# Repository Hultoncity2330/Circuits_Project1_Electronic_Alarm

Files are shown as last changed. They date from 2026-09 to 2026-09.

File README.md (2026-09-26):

# Projet Réveil Électronique

Projet de conception d’un **réveil électronique** réalisé sous **KiCad**.  
Le dépôt contient le schéma électronique, le PCB routé, les fichiers du projet KiCad ainsi que plusieurs vues du circuit final.

## Présentation du projet

L’objectif est de concevoir un réveil électronique compact capable d’afficher l’heure sur **4 digits 7 segments**, de gérer l’heure grâce à une horloge temps réel, et de proposer une interface utilisateur simple à l’aide de boutons poussoirs.

Le circuit est organisé autour d’un **Seeed Studio XIAO ESP32-S3**, utilisé comme microcontrôleur principal.

Le PCB comprend notamment :

- un **XIAO ESP32-S3** ;
- un **RTC RV-3028-C7** pour la gestion de l’heure ;
- un **IS31FL3730** pour le pilotage des afficheurs ;
- deux afficheurs doubles **DC56-11EWA**, soit 4 digits au total ;
- un buzzer pour l’alarme ;
- un transistor MOSFET **AO3400A** pour commander le buzzer ;
- quatre boutons poussoirs : `SET`, `ALARM`, `MINUS`, `PLUS` ;
- trois LED d’indication ;
- les résistances et condensateurs nécessaires au fonctionnement du montage.

## Fonctionnement général

Le **XIAO ESP32-S3** constitue le cœur du système.

Le **RV-3028-C7** fournit l’heure au microcontrôleur via le bus **I²C** (`SDA` / `SCL`).

Le **IS31FL3730** est également relié au bus I²C et pilote les deux afficheurs 7 segments. Les deux afficheurs doubles permettent d’obtenir un affichage sur quatre chiffres.

Les boutons permettent l’interaction avec le réveil :

- `SET` : réglage ;
- `ALARM` : gestion de l’alarme ;
- `PLUS` : incrémentation ;
- `MINUS` : décrémentation.

Le buzzer est commandé par le XIAO au travers du MOSFET **AO3400A**.

## Schéma électronique

Le schéma final du projet est disponible ci-dessous :

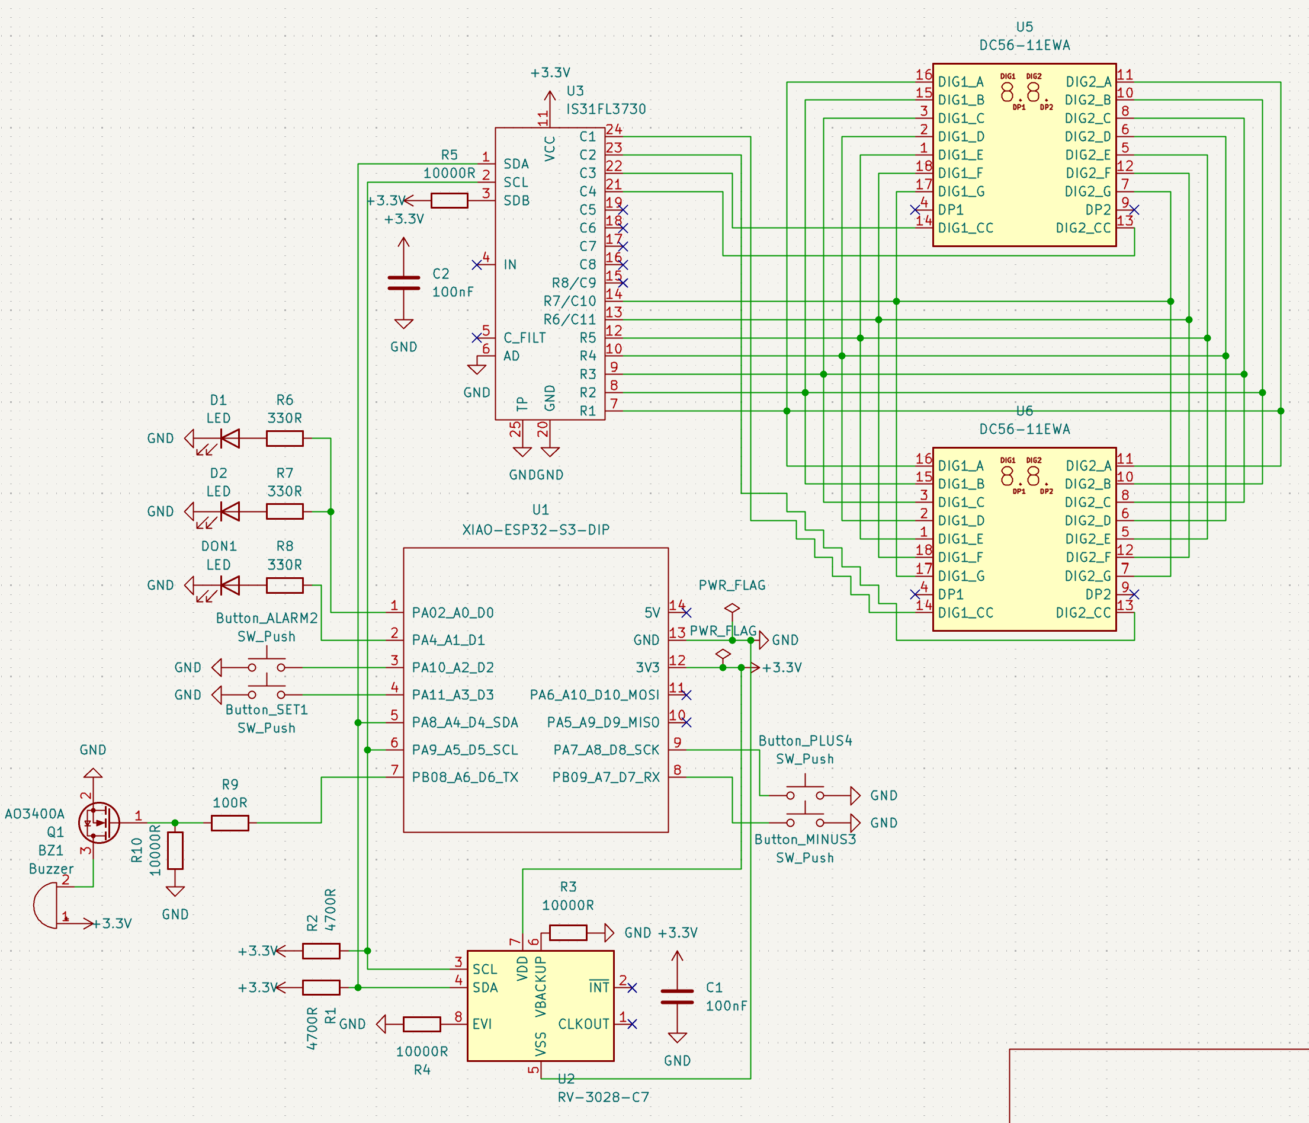
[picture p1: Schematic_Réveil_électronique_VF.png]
Final schematic


Le fichier source KiCad correspondant est :

`Projet_Réveil_électronique.kicad_sch`

## PCB

Le PCB a été placé et routé sous KiCad sur deux couches :

- **F.Cu** : couche cuivre supérieure ;
- **B.Cu** : couche cuivre inférieure.

Le routage utilise également :

- un plan de cuivre **+3.3 V** sur la face supérieure ;
- un plan de masse **GND** sur la face inférieure.

Vue du PCB final :

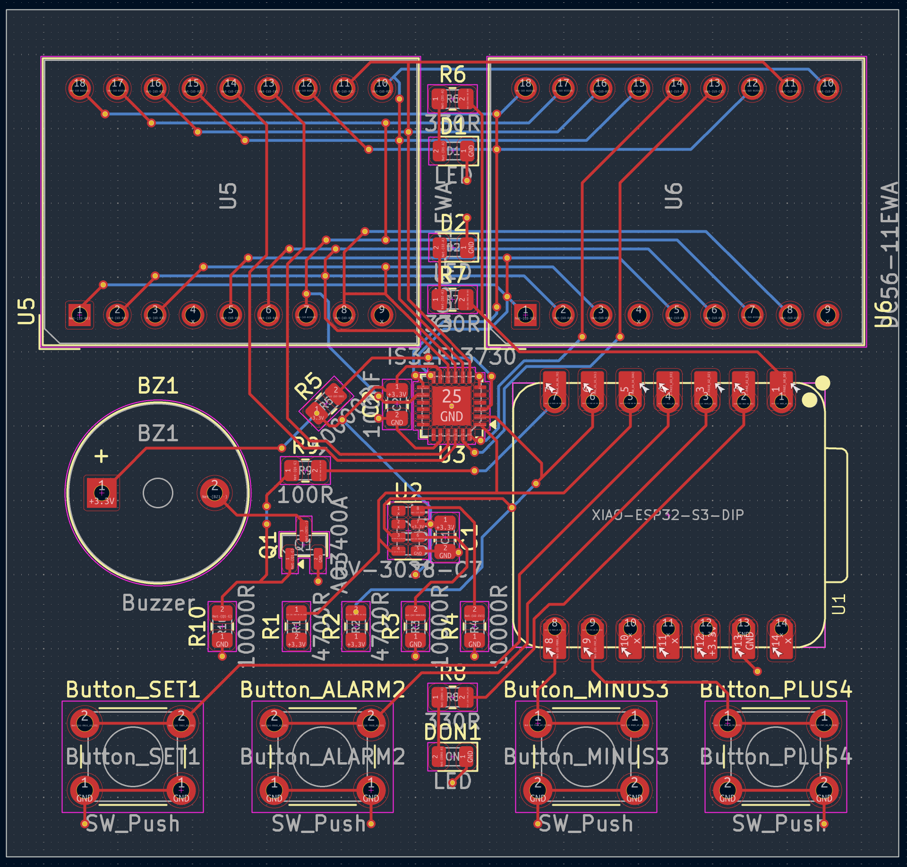
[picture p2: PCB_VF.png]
Final PCB


Le fichier source du PCB est :

`Projet_Réveil_électronique.kicad_pcb`

## Modèle 3D

### Front view

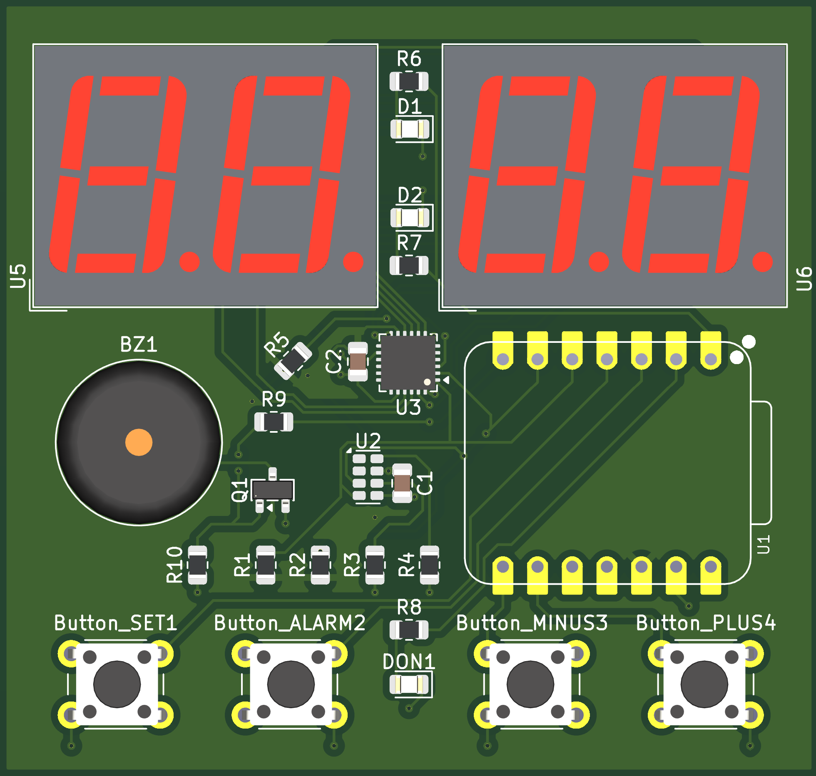
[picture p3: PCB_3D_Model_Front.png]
PCB 3D Front View


### Back view

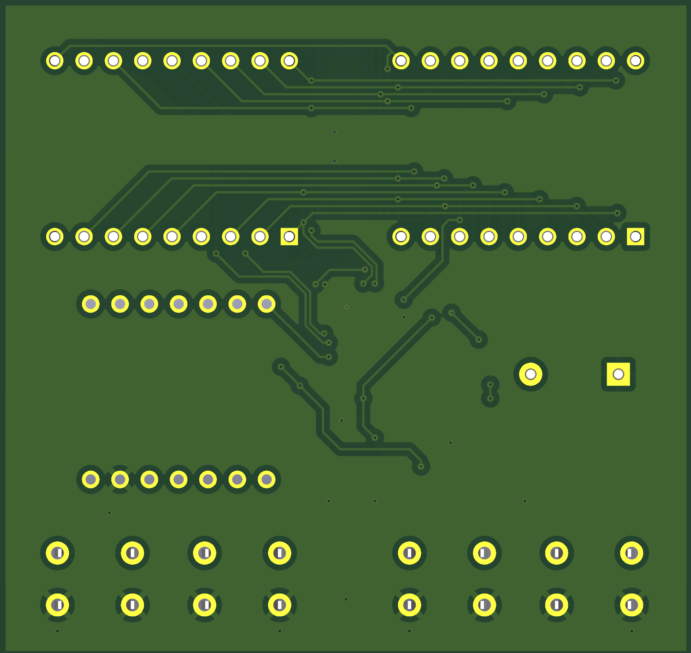
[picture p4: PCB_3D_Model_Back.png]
PCB 3D Back View


### Perspective view

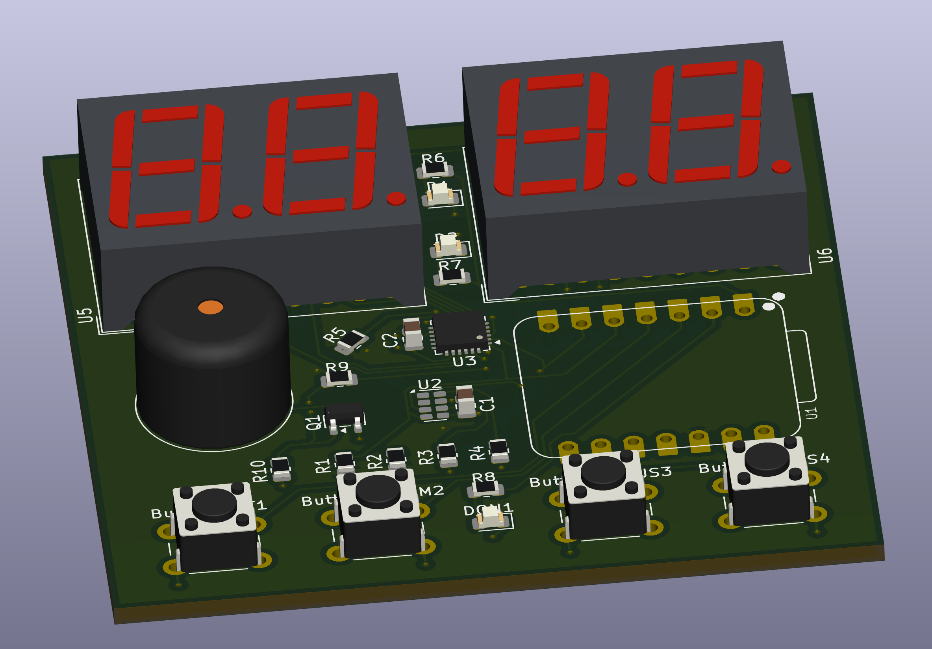
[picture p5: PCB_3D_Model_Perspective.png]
PCB 3D Perspective View


## Validation KiCad

Le projet a été vérifié avec les outils de contrôle de KiCad.

À la fin du routage :

- **ERC** du schéma : validé ;
- **DRC** du PCB : `0` erreur ;
- **Items non connectés** : `0` ;
- **Parité schématique / PCB** : `0` erreur.

Cela permet de vérifier la cohérence électrique et le routage du projet avant la fabrication.

> La validation ERC/DRC ne remplace pas un test physique du PCB assemblé.  
> Le fonctionnement réel doit être confirmé après soudure et mise sous tension.

## Structure du dépôt

```text
.
├── Projet_Réveil_électronique.kicad_pro
├── Projet_Réveil_électronique.kicad_sch
├── Projet_Réveil_électronique.kicad_pcb
├── Schematic_Réveil_électronique_VF.png
├── PCB_VF.png
├── PCB_3D_Model_Front.png
├── PCB_3D_Model_Back.png
├── PCB_3D_Model_Perspective.png
├── .gitignore
└── README.md
```

## Fichiers principaux

| Fichier | Description |
|---|---|
| `Projet_Réveil_électronique.kicad_pro` | Fichier principal du projet KiCad |
| `Projet_Réveil_électronique.kicad_sch` | Schéma électronique |
| `Projet_Réveil_électronique.kicad_pcb` | PCB routé |
| `Schematic_Réveil_électronique_VF.png` | Image du schéma final |
| `PCB_VF.png` | Vue du PCB final |
| `PCB_3D_Model_Front.png` | Vue 3D avant |
| `PCB_3D_Model_Back.png` | Vue 3D arrière |
| `PCB_3D_Model_Perspective.png` | Vue 3D en perspective |

## Auteur

Projet réalisé dans le cadre du cours `Circuits & Embedded Devices` du `21-23/09/2026`.

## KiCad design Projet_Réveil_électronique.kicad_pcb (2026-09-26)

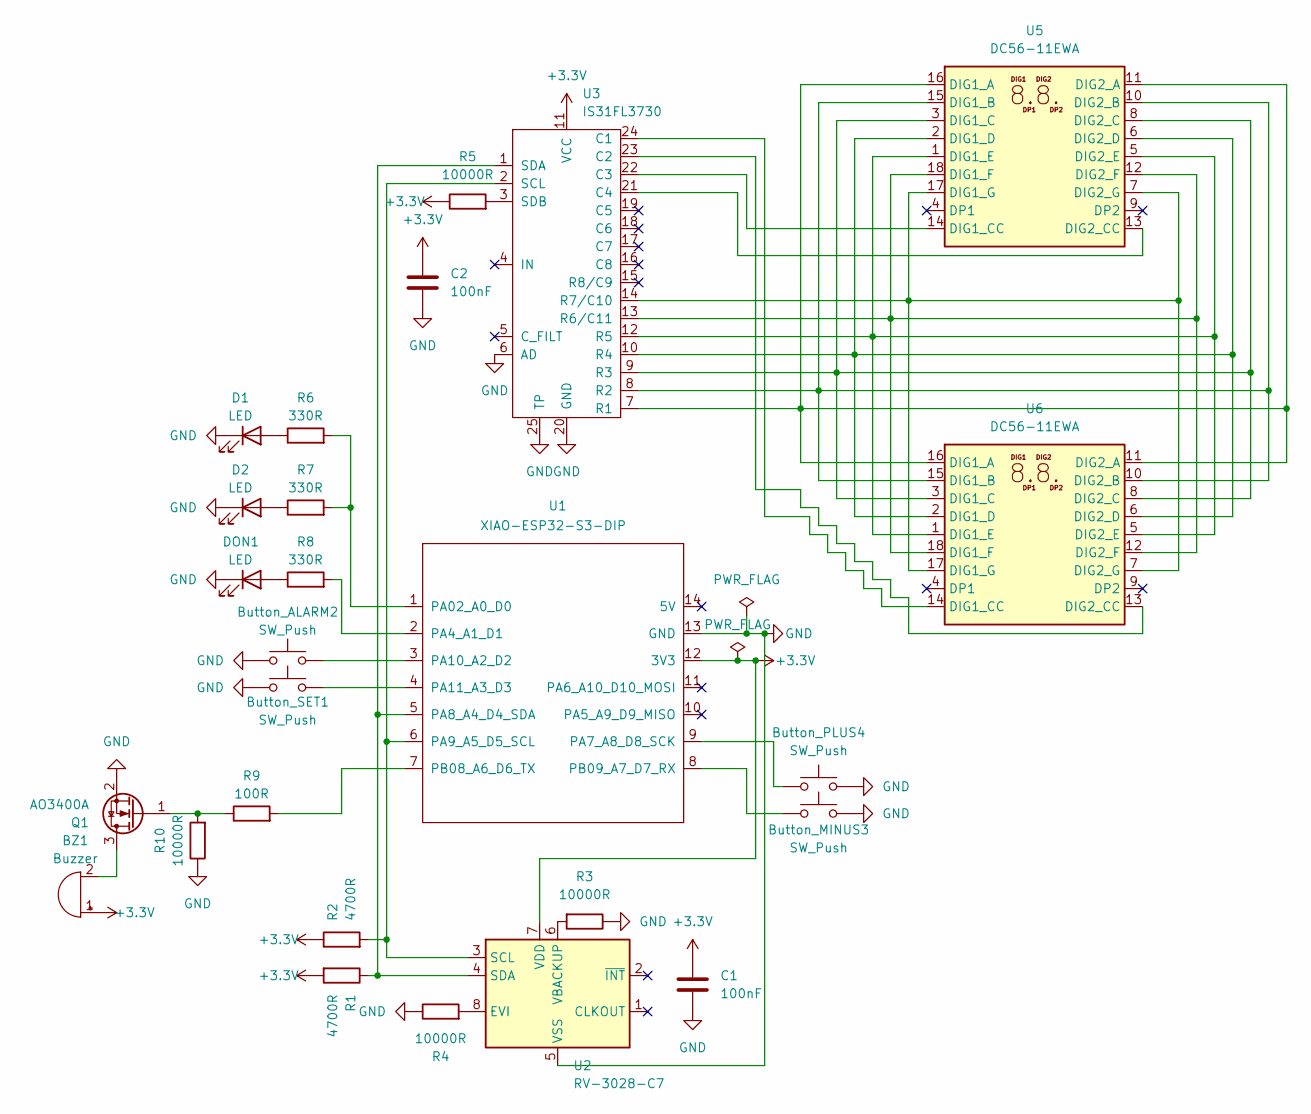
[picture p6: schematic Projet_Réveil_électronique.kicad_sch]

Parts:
BZ1: Buzzer; Buzzer_12x9.5RM7.6
Button_ALARM2: SW_Push; SW_PUSH_6mm
Button_MINUS3: SW_Push; SW_PUSH_6mm
Button_PLUS4: SW_Push; SW_PUSH_6mm
Button_SET1: SW_Push; SW_PUSH_6mm
C1, C2: 100nF; C_0805_2012Metric
D1, D2: LED; LED_0805_2012Metric
DON1: LED; LED_0805_2012Metric
Q1: AO3400A; SOT-23
R1, R2: 4700R; R_0805_2012Metric
R3, R4, R5, R10: 10000R; R_0805_2012Metric
R6, R7, R8: 330R; R_0805_2012Metric
R9: 100R; R_0805_2012Metric
U1: XIAO-ESP32-S3-DIP
U2: RV-3028-C7; MicroCrystal_C7_SON-8_1.5x3.2mm_P0.9mm
U3: IS31FL3730; QFN-24-1EP_4x4mm_P0.5mm_EP2.6x2.6mm
U5, U6: DC56-11EWA; DA56-11SURKWA

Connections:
+3.3V: BZ1.1 (+), C1.1, C2.1, R1.2, R2.1, R5.1, U1.12 (3V3), U2.7 (VDD), U3.11 (VCC)
GND: Button_ALARM2.1, Button_MINUS3.2, Button_PLUS4.2, Button_SET1.1, C1.2, C2.2, D1.1 (K), D2.1 (K), DON1.1 (K), Q1.2 (S), R3.1, R4.1, R10.1, U1.13 (GND), U2.5 (VSS), U3.6 (AD), U3.20 (GND), U3.25 (TP)
unnamed: BZ1.2 (-), Q1.3 (D)
unnamed: D1.2 (A), R6.1
unnamed: D2.2 (A), R7.1
unnamed: DON1.2 (A), R8.1
unnamed: Q1.1 (G), R9.1, R10.2
unnamed: R6.2, R7.2, U1.1 (PA02_A0_D0)
unnamed: R8.2, U1.2 (PA4_A1_D1)
unnamed: Button_PLUS4.1, U1.9 (PA7_A8_D8_SCK)
unnamed: R1.1, U1.5 (PA8_A4_D4_SDA), U2.4 (SDA), U3.1 (SDA)
unnamed: R2.2, U1.6 (PA9_A5_D5_SCL), U2.3 (SCL), U3.2 (SCL)
unnamed: Button_ALARM2.2, U1.3 (PA10_A2_D2)
unnamed: Button_SET1.2, U1.4 (PA11_A3_D3)
unnamed: R9.2, U1.7 (PB08_A6_D6_TX)
unnamed: Button_MINUS3.1, U1.8 (PB09_A7_D7_RX)
unnamed: R4.2, U2.8 (EVI)
unnamed: R3.2, U2.6 (VBACKUP)
unnamed: U3.24 (C1), U6.14 (DIG1_CC)
unnamed: U3.23 (C2), U6.13 (DIG2_CC)
unnamed: U3.22 (C3), U5.14 (DIG1_CC)
unnamed: U3.21 (C4), U5.13 (DIG2_CC)
unnamed: U3.7 (R1), U5.11 (DIG2_A), U5.16 (DIG1_A), U6.11 (DIG2_A), U6.16 (DIG1_A)
unnamed: U3.8 (R2), U5.10 (DIG2_B), U5.15 (DIG1_B), U6.10 (DIG2_B), U6.15 (DIG1_B)
unnamed: U3.9 (R3), U5.3 (DIG1_C), U5.8 (DIG2_C), U6.3 (DIG1_C), U6.8 (DIG2_C)
unnamed: U3.10 (R4), U5.2 (DIG1_D), U5.6 (DIG2_D), U6.2 (DIG1_D), U6.6 (DIG2_D)
unnamed: U3.12 (R5), U5.1 (DIG1_E), U5.5 (DIG2_E), U6.1 (DIG1_E), U6.5 (DIG2_E)
unnamed: U3.13 (R6/C11), U5.12 (DIG2_F), U5.18 (DIG1_F), U6.12 (DIG2_F), U6.18 (DIG1_F)
unnamed: U3.14 (R7/C10), U5.7 (DIG2_G), U5.17 (DIG1_G), U6.7 (DIG2_G), U6.17 (DIG1_G)
unnamed: R5.2, U3.3 (SDB)

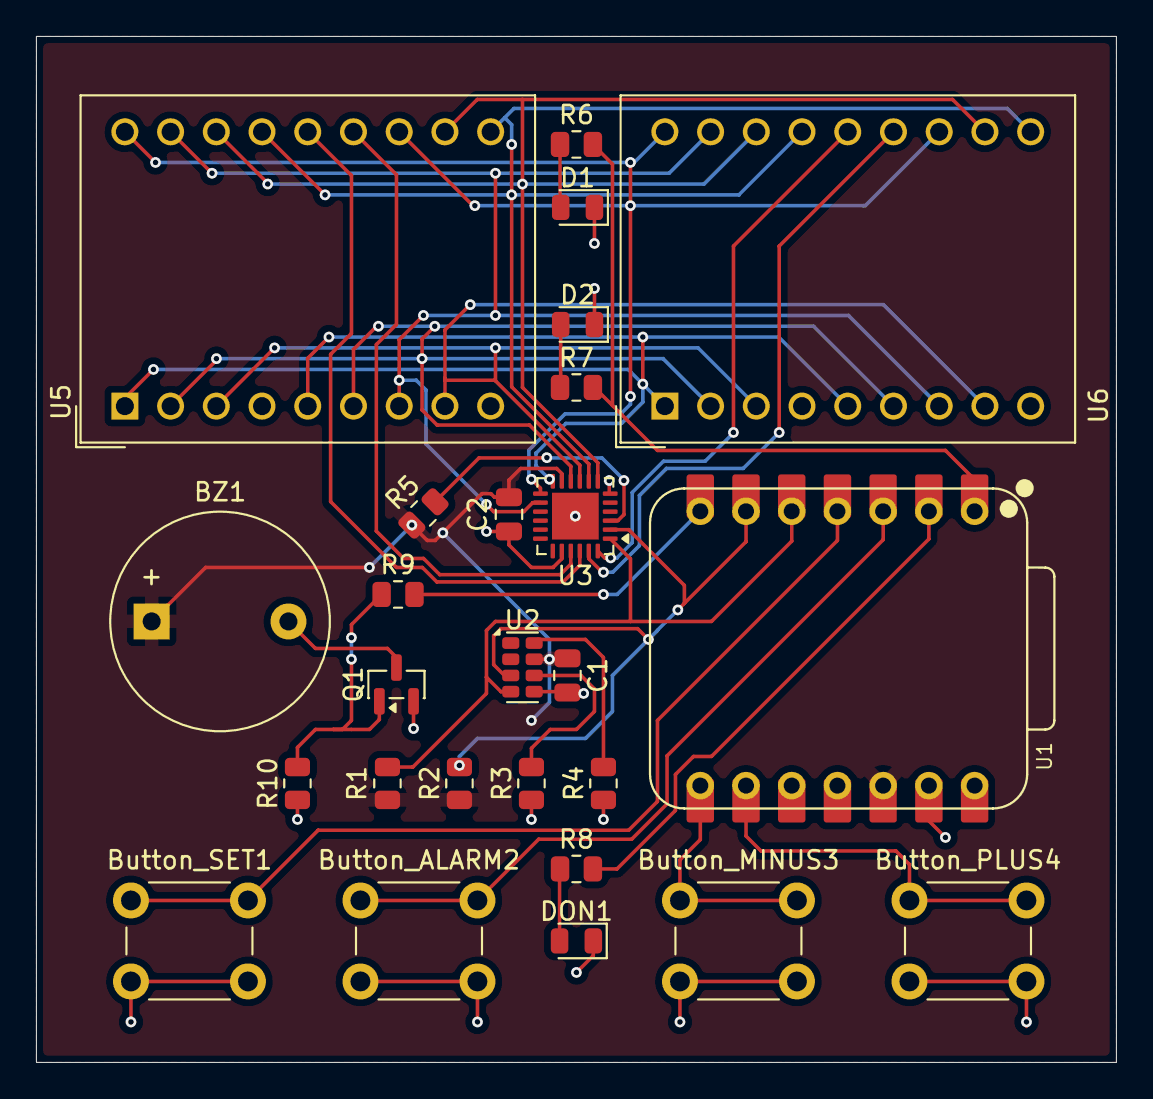
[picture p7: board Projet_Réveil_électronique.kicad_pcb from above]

Board: 2 copper layers, 60.0 x 57.0 mm, 26 parts (0 on the bottom side), 30 nets.

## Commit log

2026-09-24 [A01] Synchronisation des fichiers du projet
    [Projet_Réveil_électronique.kicad_pcb, Projet_Réveil_électronique.kicad_sch]
2026-09-24 [D03] Remove KiCad temporary files from repository
2026-09-26 [M05] - Finalize KiCad Schematic and PCB
    [Projet_Réveil_électronique.kicad_pcb, Projet_Réveil_électronique.kicad_sch]
2026-09-26 [A06] - Added final versions of Schematic and PCB images
2026-09-26 [D06b] Removed old schematic
